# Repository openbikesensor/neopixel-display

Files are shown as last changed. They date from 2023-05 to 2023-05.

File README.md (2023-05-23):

OBS-Neopixel-display
====================

All in one repo that contains (improved versions of) the firmware, case and manual for the OBS-Neopixel-display.

[start here (german build instructions)](bauanleitung/README.md)

> **Warning** If you already use the firmware on a device note that the button pin was changed in the firmware to make the Firmware compatible to both Raspberry Pi 1 and 2

References
----------
- [link to original firmware source code](https://git.chaotikum.org/malte/openbikesensor-neopixel)
- [link to original case](https://github.com/openbikesensor/8x32-neopixel-case)
- [link to original manual](https://md.dennis-boldt.de/e7RjfgLORk20s4eOPV2OUQ)

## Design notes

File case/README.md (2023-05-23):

# OpenBikeSensor 8x32-neopixel-case

Files for a case that fits the 8x32 pixel WS2812B.

There are two variants - one for large printbeds and one for the smaller printbeds of typical consumer printers. Both can be generated by running ``make -j``, to switch between the two in the openscad file, the boolean variable ``small printbed`` can be adjusted.

The software which connects to an OpenBikeSensor via Bluetooth and shows the values on the display can be found [here](https://git.chaotikum.org/malte/openbikesensor-neopixel). 

Carefully choose a power supply, consider [this](https://www.reichelt.de/led-netzteil-40-w-5-v-dc-8-a-ip67-glp-gpv-60-5-p247116.html) if you can assure power consumption will not exceed 40W.

Build instructions (in german) can be found [here](https://md.dennis-boldt.de/e7RjfgLORk20s4eOPV2OUQ)

## The closed case

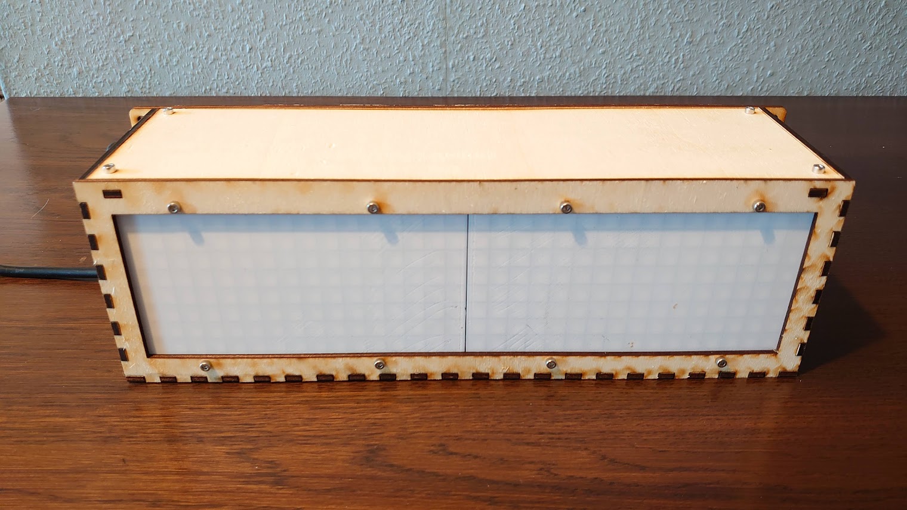
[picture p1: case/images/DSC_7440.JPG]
Front view

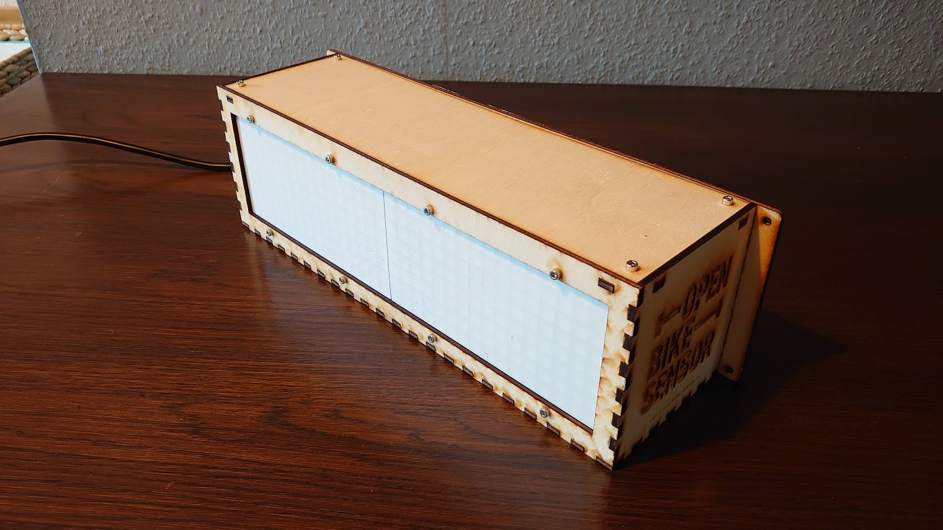
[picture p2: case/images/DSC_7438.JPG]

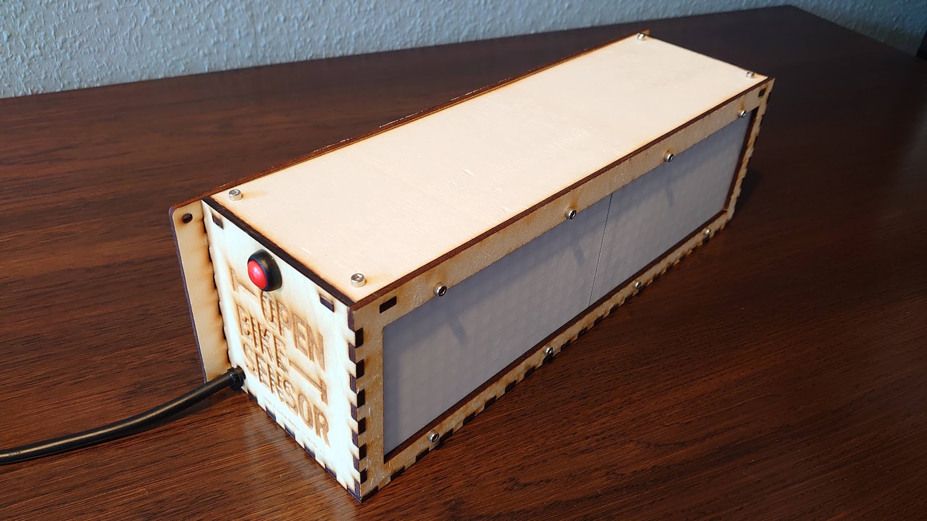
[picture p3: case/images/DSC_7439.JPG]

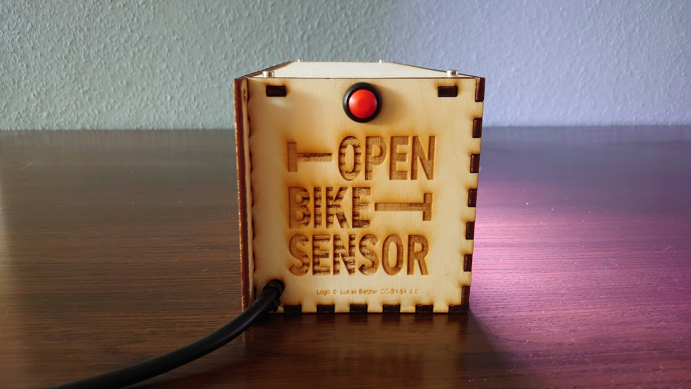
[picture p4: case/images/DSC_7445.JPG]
Side View


## The opened case

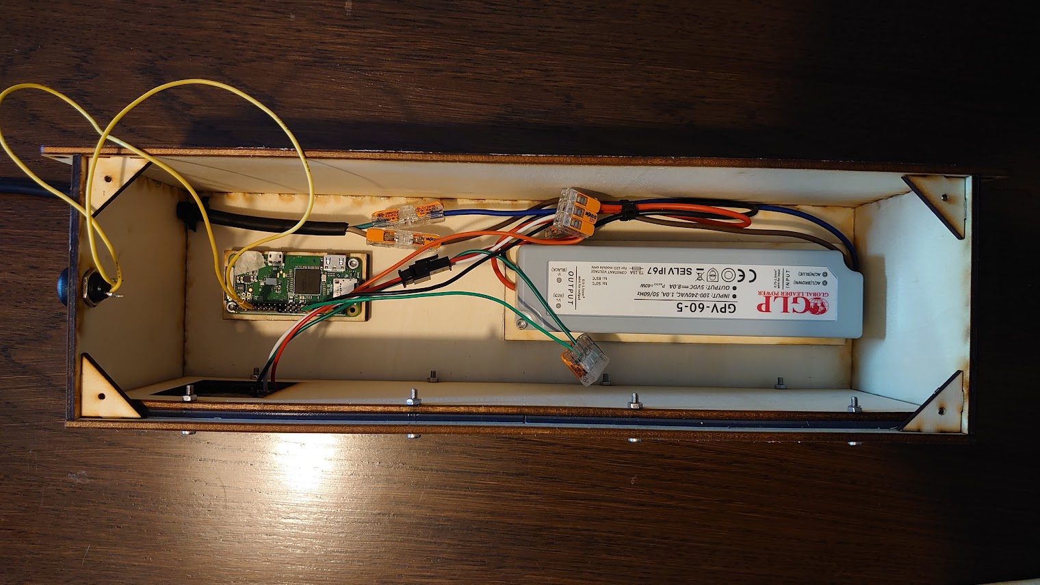
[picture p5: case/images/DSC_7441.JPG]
Drag Racing


## The case in action 

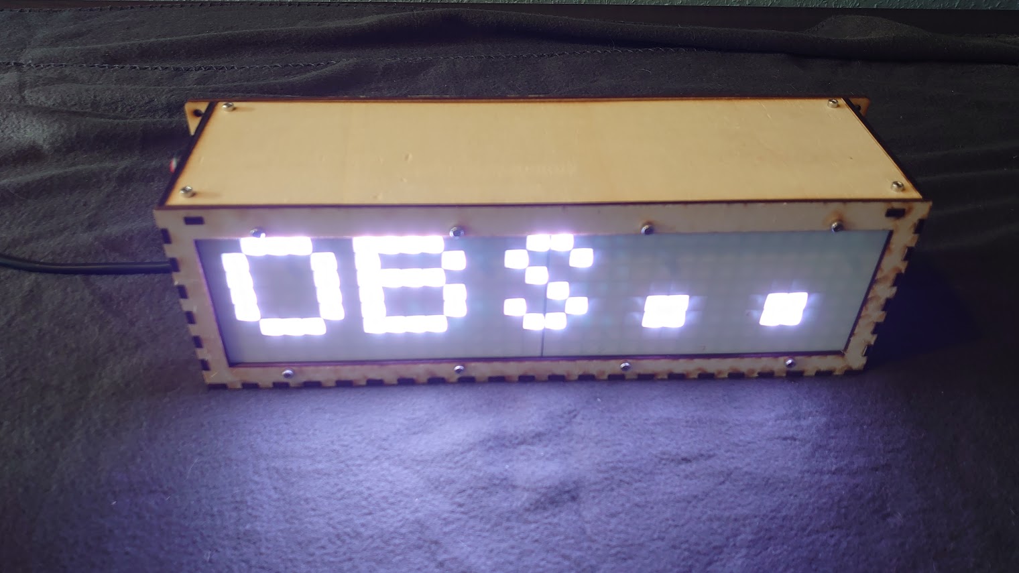
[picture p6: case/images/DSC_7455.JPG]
No OpenBikeSensor connected

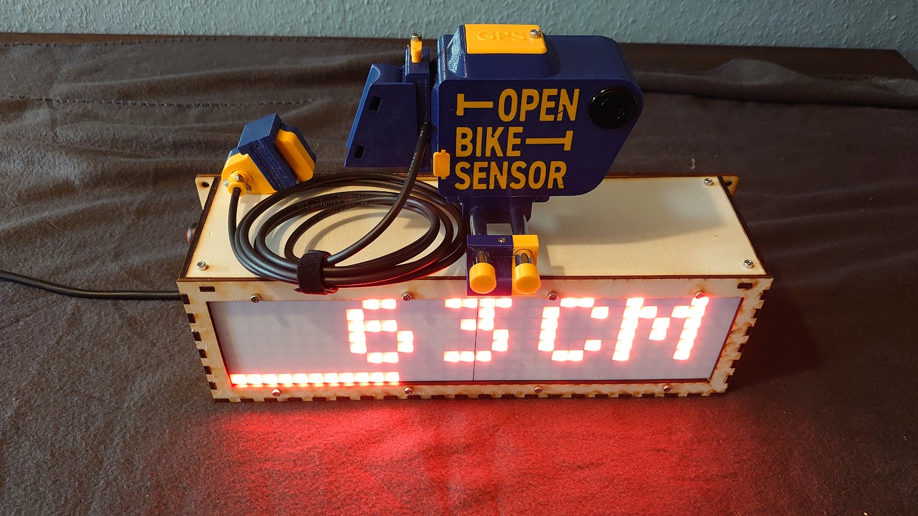
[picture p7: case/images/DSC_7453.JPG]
OpenBikeSensor is connected and distance is shown in red

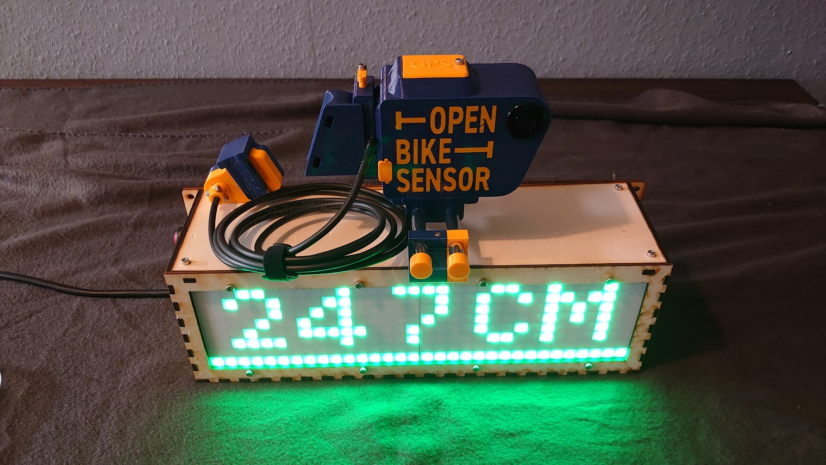
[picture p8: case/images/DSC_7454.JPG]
OpenBikeSensor is connected and distance is shown in green


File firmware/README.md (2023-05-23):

# LED-Matrix

## Dependencies

Raspberry Pi OS

```
sudo apt install python3-pip libopenjp2-7 libtiff5
sudo pip3 install pillow rpi_ws281x adafruit-circuitpython-neopixel bleak==0.14.3
```

**Hint**: Bleak 0.15 does not work!

Run with:

```
sudo python obs-neo.py
```

or for low power operation

```
sudo python obs-neo-lowpower.py
```

## Font

Font taken from https://github.com/hzeller/rpi-rgb-led-matrix/tree/master/fonts and converted with Pillow (see https://stackoverflow.com/questions/48304078/python-pillow-and-font-conversion).

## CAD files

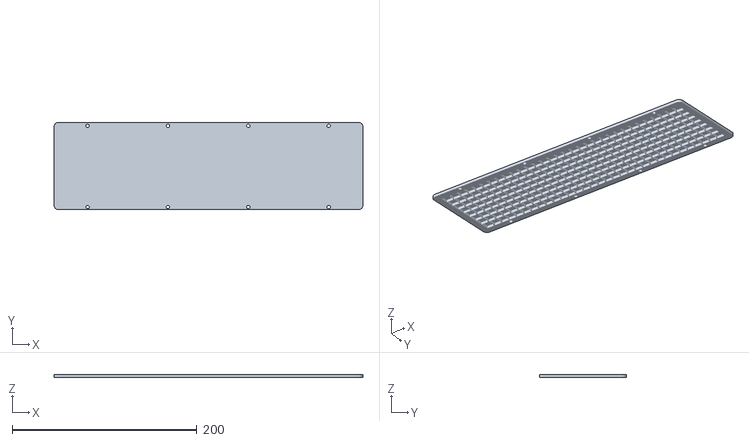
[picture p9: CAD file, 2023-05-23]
case/stls/8x32_neopixel_diffusor.stl
334.8 x 94.8 x 3.00

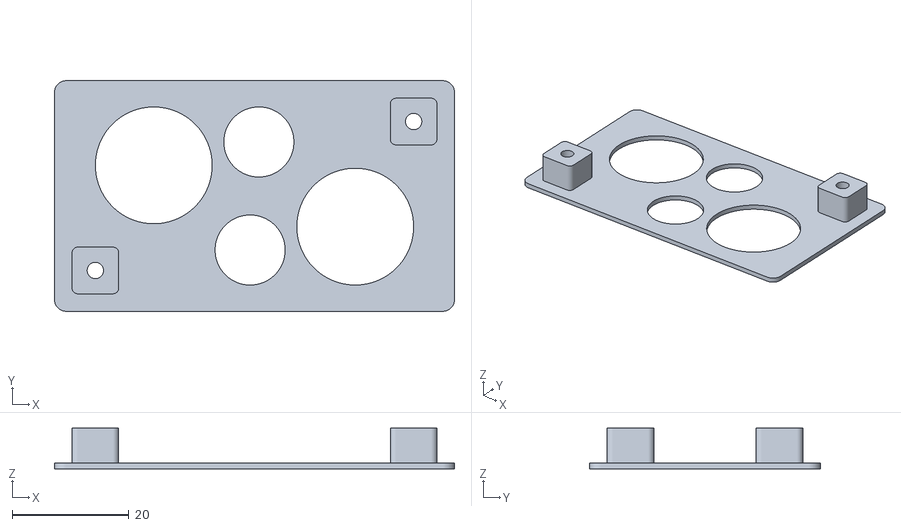
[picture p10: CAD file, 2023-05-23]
case/stls/Pi1mount.stl
68.5 x 39.5 x 7.00

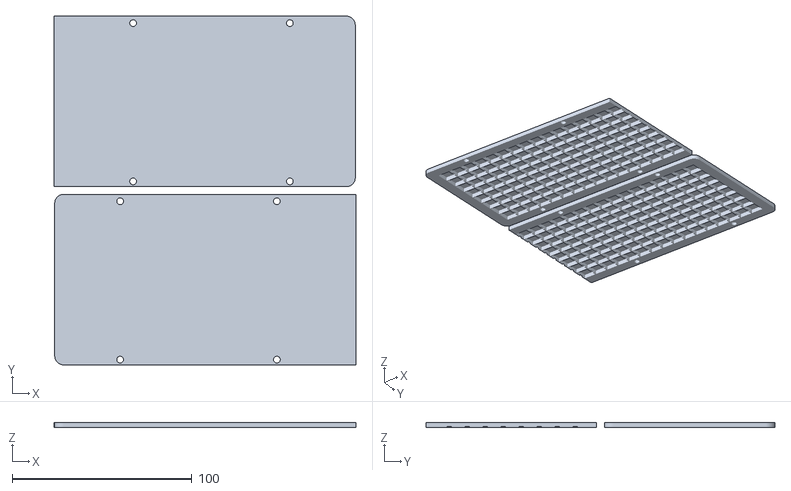
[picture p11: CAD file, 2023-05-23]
case/stls/8x32_neopixel_diffusor_small.stl
167.8 x 193.8 x 3.00

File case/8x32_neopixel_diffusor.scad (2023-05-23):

$fn = 128;

small_printbed = true;

pixel_distance = 10;
pixel_wall = 0.8;

// width_pixels = 64;
// height_pixels = 8;
width_pixels = 32;
height_pixels = 8;

cap_size = 2.6;
cap_height = 0.8;

grid_width = width_pixels * pixel_distance + pixel_wall;
grid_height = height_pixels * pixel_distance + pixel_wall;
grid_thickness = 3.0;

padding = 7;

module Diffusers() {
  thickness = 0.2;
  translate([0, 0, grid_thickness - thickness])
    union() {
      for (x = [0:width_pixels - 1], y = [0:height_pixels - 1]) {
        translate([x * pixel_distance + pixel_wall, y * pixel_distance + pixel_wall, 0])
          cube([pixel_distance - pixel_wall, pixel_distance - pixel_wall, thickness]);
      }
    }
}


module DiffuserGrid() {
  difference() {
    cube([grid_width, grid_height, grid_thickness,]);

    for (x = [0:width_pixels - 1], y = [0:height_pixels - 1]) {
      translate([x * pixel_distance + pixel_wall, y * pixel_distance + pixel_wall, - 1])
        cube([pixel_distance - pixel_wall, pixel_distance - pixel_wall, grid_thickness + 2]);
    }

    // Add a little notch in the vertical grid walls for the capacitors.
    for (y = [0:height_pixels - 1]) {
      translate([pixel_wall, (y + 0.5) * pixel_distance + pixel_wall - cap_size / 2, - 1])
        cube([grid_width - 2 * pixel_wall, cap_size, 1 + cap_height]);
    }
  }
}


module RoundedCube(dim, r) {
  hull()
    for (x = [0, 1], y = [0, 1])
    translate([x == 1 ? dim.x - r : r, y == 1 ? dim.y - r : r, 0])
      cylinder(r = r, h = dim.z);
}

module FrontPanel() {
  difference() {
    translate([- padding, - padding, 0])
      RoundedCube([grid_width + 2 * padding, grid_height + 2 * padding, grid_thickness], 5.0);

    translate([0, 0, - 2])
      cube([grid_width, grid_height, 20]);
  }
}


module ScrewConnector(negative = false) {
  intersection() {
    difference() {
      cube([14, 8, 8]);

      // insert
      translate([6, 4, 4])
        rotate([0, 90, 0])
          cylinder(d = 4, h = 6);

      // hole
      translate([0, 4, 4])
        rotate([0, 90, 0])
          cylinder(d = 3.25, h = 6);

      // head
      translate([0, 4, 4])
        rotate([0, 90, 0])
          cylinder(d = 6, h = 3);
    }

    translate([negative ? 6 : - 100 + 6, 0, 0])
      cube([100, 8, 8]);
  }
}

module ScrewHole() {
  // hole
  translate([0, 0, - 1])
    rotate([0, 0, 0])
      cylinder(d = 3.75, h = 6);
}


module FrontPanelWithHoles() {
  color([1, 1, 1])
    Diffusers();
  DiffuserGrid();
  //FrontPanel();

  difference() {
    FrontPanel();
    for (i = [29.35:87.1:290.65]) {
      for (j = [- 4.05, 83.903]) {
        translate([i, j, 0]) ScrewHole();
      }
    }
  };
}

  if (small_printbed) {
    intersection() {
      FrontPanelWithHoles();
      translate([- 30, - 10, 0])cube([16 * pixel_distance + pixel_wall / 2 + 30, 400, 8]);
    }
    translate([16*pixel_distance-padding,8*pixel_distance+2*padding+5])mirror([1,0,0])intersection() {
      FrontPanelWithHoles();
      translate([- 30, - 10, 0])cube([16 * pixel_distance + pixel_wall / 2 + 30, 400, 8]);
    }
  } else {
    FrontPanelWithHoles();
  }


//ScrewConnector(false);

//rotate([0,90,0])
//translate([-10, 10, ])
//ScrewConnector(true);

// part = "black";
//
// translate([0, 0, grid_thickness])
// rotate([180, 0, 0]) {
//     if (part == "white") {
//         Diffusers();
//     } else {
//         DiffuserGridBottom();
//     }
// }



// translate([0, 0, 3])
// DiffuserGrid(2.0);

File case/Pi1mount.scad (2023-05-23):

$fn=100;
size=[85,56];
holes=[[25.5,18],size - [5,12.5]];

linear_extrude(1)difference(){
   offset(2)translate(holes[0]-[5,5])square(holes[1]-holes[0]+[10,10]);
   translate(holes[0]+[10,18])circle(10);
   translate(holes[1]-[10,18])circle(10);
   translate(holes[1]-[28,22])circle(6);
   translate(holes[0]+[28,22])circle(6);
    for (h = holes)      translate(h)circle(d=2.8);

}
linear_extrude(7)for (h = holes) {
    difference(){
      translate(h)offset(1)square([6,6],center=true);
      translate(h)circle(d=2.8);
    }
}

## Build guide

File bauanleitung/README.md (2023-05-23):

###### tags: `obs` `raspi`

# OBS mit Neopixel-Display am Raspi-Zero

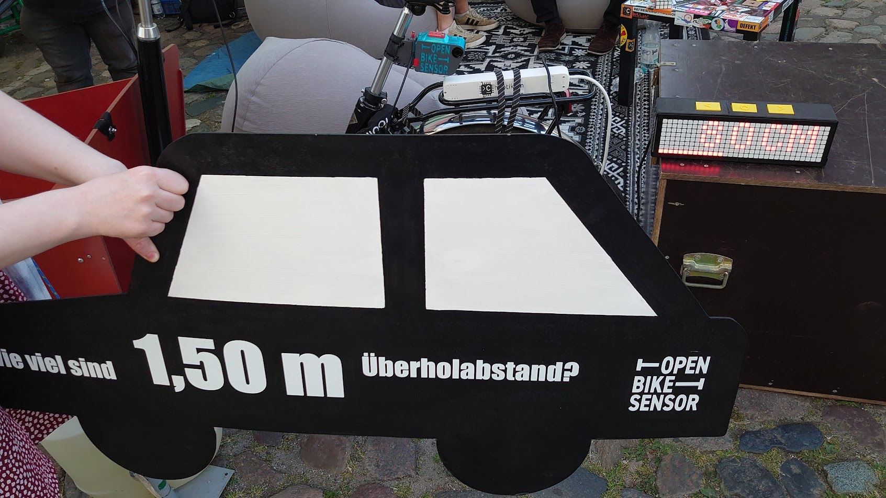
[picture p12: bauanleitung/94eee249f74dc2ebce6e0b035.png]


## Motivation

Dieses Dokument beschreibt, wie die Sensorwerte des OBSs auf einer Neopixel-LED-Matrix an einem RasperryPi Zero W angezeigt werden.

> **Warning**
> Dieses Dokument zeigt (noch) ein 3D-gerucktes Gehäuse. Praktisch sind wir inzwischen 
> bei einem Holzgehäuse angekommen.

> **Warning**
> Gegenüber früheren Versionen hat sich der Standardpin für den Button geändert - Falls du schon ein Gerät besitzt, musst du ggf. den Button pin in der für dich passenden `.py` Datei anpassen.

### Links

* [Software](../firmware)
* [Gehäuse](../case)

## Benötigtes Material

* Holz-Gehäuse:
    * [hier im Repo](../case)
* Für Pi zero: [pi zero schraubplatte zum einkleben](https://www.printables.com/model/218525-raspberry-pi-zero-pi-plates)
* Alternativ: [Pi 1 platte zum einkleben](../case/stls/Pi1mount.stl)
* LED-Display:
    * https://www.aliexpress.com/item/1005003867884387.html
* Für Netzbetrieb:
  * Netzteil:
      * https://www.reichelt.de/de/de/led-netzteil-40-w-5-v-dc-8-a-ip67-glp-gpv-60-5-p247116.html
  * 230V-Strom-Kabel
* Für Mobilbetrieb/USB
  * https://www.ebay.de/itm/204023838928?var=504451165442
  * Achtung: Zieht 2-3A in der Spitze und braucht eine dicke Powerbank oder ein ordentliches USB-Netzteil. Im Branch 
* 2x Wago-Klemmen (3er)
* RaspiPi-Zero W oder besser Zero W2
    * HDMI-Adapter (optional)
    * microUSB-Adapter (optional)
    * mciroUSB-Netzteil 
* Alternativ gehen auch Pi2, Pi3, Pi4 oder Pi1+ [USB Bluetooth adapter](https://www.amazon.de/gp/product/B08B9WQFTL/ref=ppx_yo_dt_b_search_asin_title?ie=UTF8&psc=1)
* Diverse Kabel für Anschluss des Displays/Raspis
* microUSB-Kartenleser/-Adapter
* Kabelbinder

## Hardware

### Warum 230V?
Damit ist auf jeden Fall luft für:
* Das Display hat 8x32 RGB-LEDs = 256 LEDs
* Je Farbe werden 20mA benötigt. Wenn alle 3 Farben voll aufgedreht sind, dann leuchtet es weiß und dann sind das **60mA pro LED**
* Heißt: 256 LEDs * 60mA/LED = 15360mA = ~15A (bei 5V also 75 Watt)
* Wir gehen davon aus, dass maximal die Hälfte der LEDs verwendet wird, also max. 7,5 A (37,5 Watt). Das verwendete Netzteil liefert 8A (40 Watt).
* Das schafft kein 5V-USB-Netzteil / keine 5V-Powerbank, wenn man noch etwas auf dem Display erkennen will.

### Was sind die Limits, wenn wir doch USB-C wollen?
* Tatsächlich benutzen wir deutlich weniger als die Hälfte der LEDs
* Wir können statt weiß genausogut in einer anderen Farbe anzeigen, reingrün z.B. braucht nur 1/3 des Stroms für Weiß
* Damit Weiß genauso hell ist wie z.B. Grün, reicht es grob, weiß aus 128,128,128 zu bauen, und es verbraucht dann nur die Hälfte.
* Gemessen braucht das Display in der Urvariante etwa 2.5A-3A, eine angepasste Variante (``obs-neo-lowpower.py``,``run_lowpower.sh``) braucht nur 1.5-2.1A

### Zusammenbau
* Pin-Belegung des Raspi:
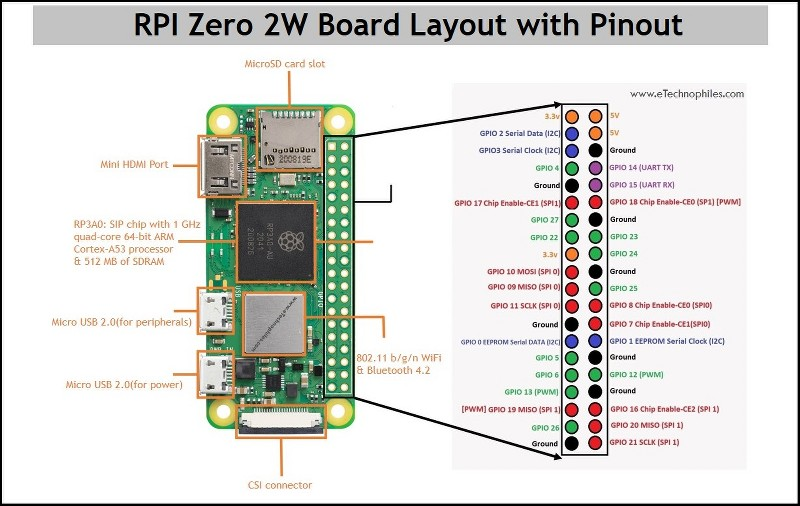
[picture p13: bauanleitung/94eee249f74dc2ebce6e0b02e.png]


* **Bei Netzbetrieb**
  * Das 230V-Strom-Kabel von Hinten durch das Gehäuse legen
  * Das Netzteil in das Gehäuse legen und mittels Wago-Klemmen mit dem 230V-Strom-Kabel verbinden (braun mit braun, blau mit blau)
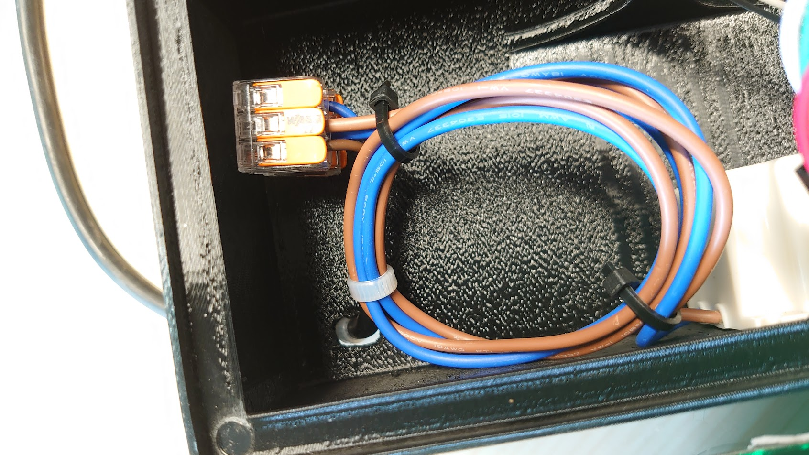
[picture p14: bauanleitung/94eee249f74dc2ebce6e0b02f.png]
      
  * Das 5V-Kabel des Netzteils (rot) verbinden:
      * Mit dem Display (rot) 
      * Mit dem 5V-Pin des Raspis (auf der Grafik oben rechts)
  * Das GND-Kabel des Netzteils (schwarz) verbinden:
      * Mit dem Display (weiß)
      * Mit dem Ground-Pin des Raspis (auf der Grafik oben rechts)

* **Bei USB-Betrieb**

  * Kabel an USB-C-Buchse anlöten (rot an "V"/+, schwarz an "G"/-)
  * Mittels Wago-klemme verbinden wie oben
  * Mit Cuttermesser an geeigneter Stelle Loch für Buchse schneiden
  * Mit Heißkleber fixieren. 
    
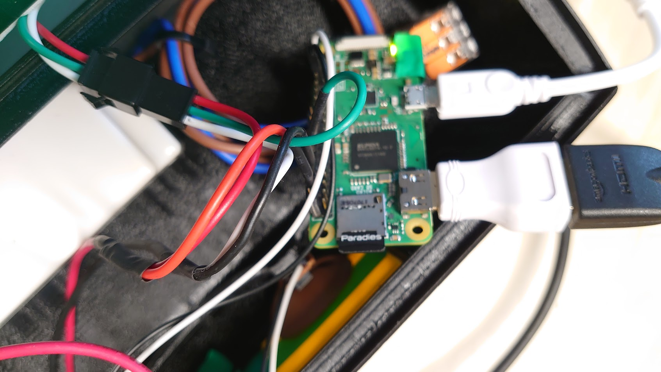
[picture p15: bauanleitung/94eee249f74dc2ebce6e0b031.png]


* Das Daten-Kabel des Displays mit (grün) mit dem GPIO18 (D18) des RaspiZero verbinden (6ter Pin von oben auf der Grafik oben rechts)
* Den Button zum Ein- und Ausschalten des Displays mit dem GPIO 17 und GND

> **Warning** Bild zeigt nicht die beschribene Pinkonfiguration für den Button pin
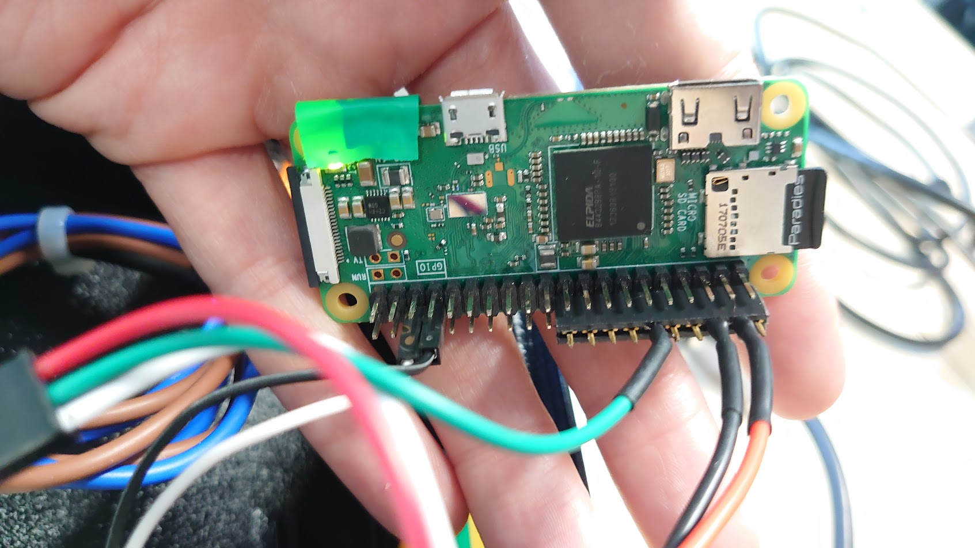
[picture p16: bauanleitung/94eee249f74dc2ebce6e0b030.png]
  

## Software

Das OS des in dieser Anleitung verwendeten PCs ist ein Ubuntu 22.04.
    
### Basis-Inbetriebnahme des Raspis
#### Komfortable alternative:
* **Raspberry Pi OS Lite** installieren und herunterladen mit PiImager. Dabei kann man direkt WLAN, username/passwort, Tastaturlayout etc konfigurieren.
  * Mit Micro usb mit strom versorgen
  * Im Router die IP nachschauen
  * Per SSH einloggen

#### Manuelle alternative:
* **Raspberry Pi OS Lite** von hand herunterladen
    * https://www.raspberrypi.com/software/operating-systems/#raspberry-pi-os-32-bit
    * Raspberry Pi OS Lite (ohne Desktop)
* Image auf eine microSD flaschen
    * microUSB-Karte mit Adapter/Kartenleser in den PC einstecken 
    * Rechtsklick auf Image -> Mit **Schreiber von Laufferksabbildern** öffnen
* Raspi anschließen:
    * PiZero mittels HDMI-Adapter an HDMI
    * Tastatur mittels microUSB-Adapter
    * microSD-Karte in den Raspi stecken
    * Strom via micro-USB anschließen. 
    * Der Raspi sollte nun starten.

### Konfiguration beim ersten Boot

* Deutsches Tatstaurlayout wählen
* Username: `pi`
* Passwort: `pi` (anpassen)

Mit den Userdaten einloggen.
    
### WLAN

* `sudo raspi-config`
    * 1 System-Options -> S1 Wireless LAN
        * Country: DE Germany
        * SSID + Password
        * Mit "Finish" bestätigen
* Reboot bestätigen (ggf. manuell mit `reboot` durchführen)
* Nach dem Neustart das WLAN prüfen:
    * `ifconfig wlan0`
    * IP-Adresse ermitteln: `<IP>`

### SSH aktivieren

* `sudo raspi-config`
    * 3 Interface Options -> I2 SSH
    * SSH-Server aktivieren
* Test vom PC:
    * `ssh pi@<IP>`

> **Note**
> Ab hier loggen wir uns via SSH auf den Raspi ein

#### Hostname (Optional)
    
* `sudo raspi-config`
    * 1 System-Options -> S4 Hostname
* Test vom PC:
    * `ssh pi@<Hostname>`
    
### Update

* `sudo apt update`
* `sudo apt upgrade`

> **Note**
> Dies kann einige Minuten dauern, da der Raspi keinen "dicken" Prozessor hat. In der Zwischenzeit den nächsten Schritt vorbereiten

### Bluetooth testen

#### OBS vorbereiten

* Miitels WLAN in die Konfiguration des Pi wechseln
    * Bluetooth aktivieren
        * General -> Operation -> Enable Bluetooth
        * Speichern `[SAVE]`
* OBS neustarten
    * Im Display sollte `Bluetooth up` zu sehen sein

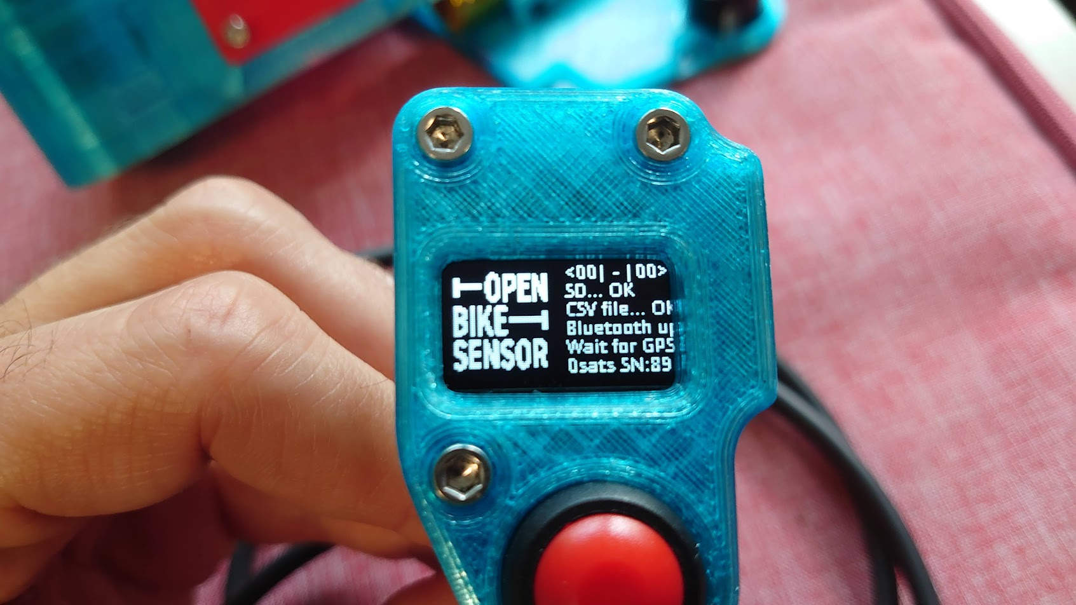
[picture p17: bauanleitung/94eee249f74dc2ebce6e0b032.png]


#### Bluetooth am RasPi

* Bluetooth verfügbar?
    * `dmesg | grep -i bluetooth`
* `bluetoothctl`
    * `scan on` tippen
    * > [NEW] Device 9C:9C:1F:C4:A3:7E OpenBikeSensor-7ca3
    * `exit` tippen

### Git

* Installation:
    * `sudo apt install git`

### Python

* Installation:
    * `sudo apt install python3`
* Version prüfen:
    * `python --version`
    * Python 3.9.2

### Installation der Python-Software

* Original Quelle:
    * https://git.chaotikum.org/malte/openbikesensor-neopixel
* Weiterentwickelter Source Code:
    * https://github.com/openbikesensor/neopixel-display
* Projekt clonen:
    * `git clone https://github.com/openbikesensor/openbikesensor-neopixel.git`
* In das Projekt wechseln:
    * `cd openbikesensor-neopixel/firmware`
* :warning: **Dependencies installieren entsprechend der README** :warning:
    * https://github.com/openbikesensor/neopixel-display
* Script starten:
    * `sudo python obs-neo.py` oder für low-power USB Betrieb`sudo python obs-neo-lowpower.py` 
    * Es sollte auf dem Display "OBS..." auftauchen, während er versucht sich mit dem OBS zu verbinden.
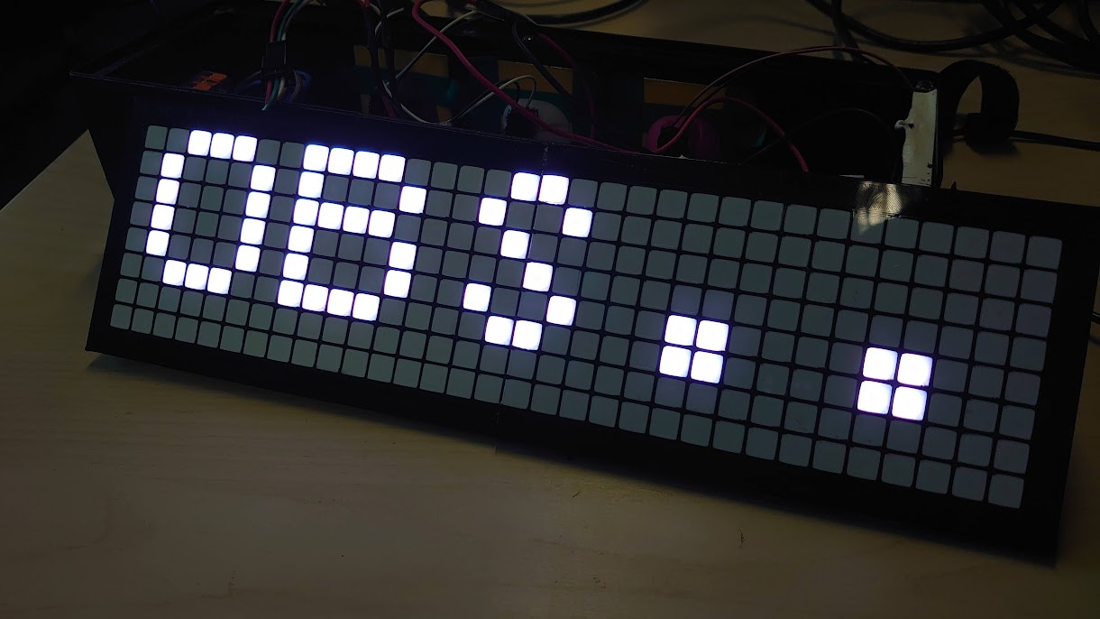
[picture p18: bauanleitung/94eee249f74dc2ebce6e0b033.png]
    * 
    * Nachdem der OBS eingeschaltet wurde, sollte der linke Sensorwert angezeigt werden: 
        * **Anmerkung**: Es wird nach einem Bluetooth-Device gesucht, dessen Name mit `OpenBikeSensor` beginnt.
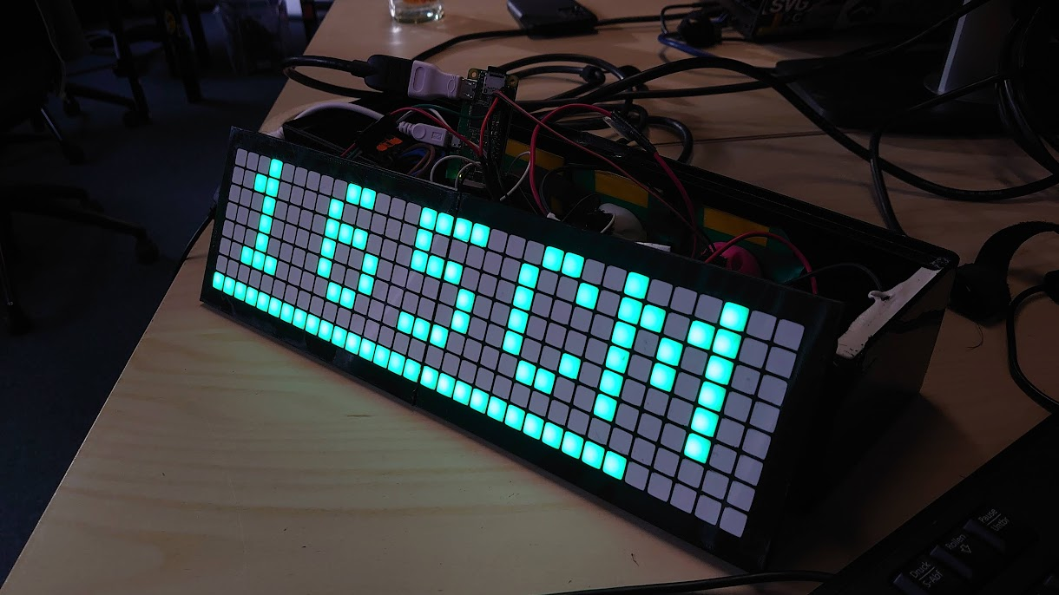
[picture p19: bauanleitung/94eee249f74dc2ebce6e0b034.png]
    * 
* Den OBS aus- und wieder einschalten. Er sollte sich immer wieder verbinden.
    
### Autostart des Python-Scripts

* In der `run.sh` die MAC-Adresse des OBS eintragen
* Script als root testen:
    * `sudo -s`
    * `/home/pi/openbikesensor-neopixel/firmware/run_lowpower.sh /home/pi/openbikesensor-neopixel/firmware`
* Wenn das klappt, dann als root:
    * `crontab -e`
    * Für die Netzteilvariante: `@reboot /home/pi/openbikesensor-neopixel/firmware/run.sh /home/pi/openbikesensor-neopixel/firmware`
    * Für Powerbank: `@reboot /home/pi/openbikesensor-neopixel/firmware/run_lowpower.sh /home/pi/openbikesensor-neopixel/firmware`
* Nun sollte das Script bei einem Boot des Raspis starten
    * `sudo reboot now`
* Das Display sollte sich mich dem OBS (wie zuvor) verbinden
* OBS und Display sollte man ab sofort in beliebiger Reihenfolge ein- und ausschalten können.
    
## Demo-Aufbau
    
* OBS am Fahrrad montieren und ggf. mit USB-C mit Strom versorgen
    * Lenkerabstand am OBS richtig einstellen, wird per Bluetooth vom Display übernommen
* Das Display in die Nähe stellen und mit Strom versorgen
* Eine Holzplatte als Refelktionsfläche verwenden
* Viele Spannende Gespräche führen :bicyclist:

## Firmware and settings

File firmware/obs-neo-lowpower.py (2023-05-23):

import sys
import asyncio
import platform
import struct
from threading import Thread

## Neopixel
import time
import board
import neopixel
from PIL import Image, ImageFont, ImageDraw

from collections import deque
from statistics import median

# OBS Bluetooth
from bleak import BleakClient, BleakScanner

# setup GPIO
import RPi.GPIO as GPIO

GPIO.setmode(GPIO.BCM)

OBS_MAC = "40:91:51:9B:6E:22"
HANDLEBAR_OFFSET_UUID = "1FE7FAF9-CE63-4236-0004-000000000004"

BUTTON = 17
ARRANGEMENT = "8x32"  # "32x8"

handlebar_left = 30

GPIO.setup(BUTTON, GPIO.IN, pull_up_down=GPIO.PUD_UP)
last_button = GPIO.input(BUTTON)

##############################
# Prepare Neopixel
##############################

# Choose an open pin connected to the Data In of the NeoPixel strip, i.e. board.D18
# NeoPixels must be connected to D10, D12, D18 or D21 to work.
pixel_pin = board.D18

# The number of NeoPixels
num_pixels = 256

# The order of the pixel colors - RGB or GRB. Some NeoPixels have red and green reversed!
# For RGBW NeoPixels, simply change the ORDER to RGBW or GRBW.
ORDER = neopixel.GRB
pixels = neopixel.NeoPixel(pixel_pin, num_pixels, brightness=1, auto_write=False, pixel_order=ORDER)

display_on = True

#
# Blutooth scanner config
#

timeout_seconds = 20
obs_address = None

i = 0
last = deque(maxlen=3)


def notification_handler(sender, data):
    global display_on, i, handlebar_left

    """Simple notification handler which prints the data received."""
    t, lraw, r = struct.unpack("Ihh", data)

    last.append(lraw)
    l = median(last)
    l -= handlebar_left
    i += 1
    if i % 2:
        return
    print(f"sensortime: {t}, Left distance {l}, right distance {r} last {last}")
    if l == -1 - handlebar_left:
        show_text_on_display("___CM", (160, 128, 128))  # white
    elif l < 0:
        show_text_on_display("XXXXX", (255, 0, 0), 0)
    elif l < 100:
        show_text_on_display(" " + str(l) + "CM", (255, 0, 0), l * 32 / 200)  # red
    elif l < 150:
        show_text_on_display(str(l) + "CM", (128, 128, 0), l * 32 / 200)  # yellow
    else:
        show_text_on_display(str(l) + "CM", (0, 128, 0), l * 32 / 200)  # green


def show_text_on_display(text, fill, length=None):
    image = Image.new('RGB', (32, 8), color="black")
    draw = ImageDraw.Draw(image)

    if display_on:
        font = ImageFont.load("6x9.pil")
        draw.text((1, -1), text, fill=fill, font=font)
        if length:
            draw.line([(0, 7), (length, 7)], fill, 1)

    for x in range(0, 32):
        for y in range(0, 8):
            if ARRANGEMENT == "8x32":
                i = x * 8
                if x % 2 == 0:
                    i += 7 - y
                else:
                    i += y
            elif ARRANGEMENT == "32x8":
                i = y * 32
                if y % 2 == 1:
                    i += 31 - x
                else:
                    i += x
            pixels[255 - i] = image.getpixel((x, y))
    pixels.show()


def read_button():
    global display_on

    while True:
        current_button = GPIO.input(BUTTON)

        if last_button and not current_button:
            print("BUTTON pressed")
            display_on = not display_on
            time.sleep(1)

        current_button = last_button
        time.sleep(0.2)


async def main(address, char_uuid):
    # read input
    t = Thread(target=read_button)
    t.daemon = True
    t.start()

    await connect(address, char_uuid)


bt_connected = False


async def connect(address, char_uuid):
    global bt_connected, handlebar_left

    def disconnected_callback(client):
        global bt_connected
        print("DISCONNECTED")
        bt_connected = False

    async with BleakClient(address, disconnected_callback=disconnected_callback) as client:
        global handlebar_left
        print(f"Connected: {client.is_connected}")
        await client.start_notify(char_uuid, notification_handler)
        handlebar = await client.read_gatt_char(HANDLEBAR_OFFSET_UUID)
        handlebar_left, trash = struct.unpack("hh", handlebar)
        print(f"handlebar_left: {handlebar_left}")
        bt_connected = True
        while True:
            if not bt_connected:
                break
            await asyncio.sleep(0.5)


class MyScanner:
    def __init__(self):
        self._scanner = BleakScanner()
        self._scanner.register_detection_callback(self.detection_callback)
        self.scanning = asyncio.Event()

    def detection_callback(self, device, advertisement_data):
        global obs_address
        if device.name.startswith("OpenBikeSensor"):
            print(device)
            obs_address = device.address
            self.scanning.clear()

    async def run(self):
        global obs_address
        print("Scan for devices")
        show_text_on_display("OBS...", (0, 0, 150))  # white
        obs_address = None
        await self._scanner.start()
        self.scanning.set()
        end_time = loop.time() + timeout_seconds
        while self.scanning.is_set():
            if loop.time() > end_time:
                self.scanning.clear()
                print('Scan has timed out so we terminate')
            await asyncio.sleep(0.1)
        await self._scanner.stop()
        if obs_address == None:
            raise Exception('No OBS found')


my_scanner = MyScanner()
loop = asyncio.get_event_loop()


def run():
    loop.run_until_complete(my_scanner.run())

    CHARACTERISTIC_UUID = "1FE7FAF9-CE63-4236-0004-000000000002"
    ADDRESS = (
        obs_address
        #        if platform.system() != "Darwin"
        #        else "B9EA5233-37EF-4DD6-87A8-2A875E821C46"
    )

    asyncio.run(
        main(ADDRESS, CHARACTERISTIC_UUID)
    )


while True:
    try:
        run()
    except Exception as e:
        print(str(e))
        print("ERROR. Retry")

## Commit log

2023-05-23 Combine everything, adapt manual for low power variant.
    [8x32_neopixel_diffusor.scad, 8x32_neopixel_diffusor.stl, 8x32_neopixel_diffusor_small.stl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]
2023-05-23 fix pin name
